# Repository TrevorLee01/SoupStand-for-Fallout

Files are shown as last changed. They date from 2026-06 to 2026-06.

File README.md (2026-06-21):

# Soup-Stand 🎧🦝 // FALLOUT PROJECT
A multifunctional pastel and tanuki (Soup!) themed headphone stand with integrated speaker, storage, and cable organization.

Created by Youna Son & Trevor Lee for Fallout / Hack Club.
✍️(◔◡◔)

ONSHAPE LINK: https://cad.onshape.com/documents/8000dcbb44917720ecbb4f72/w/cf3f842479549c0ffed44f74/e/c42a8c0b9d5092f488456cc3

  BOM INCLUDED IN THE FILES! "BOM.csv" 
or:
https://docs.google.com/spreadsheets/d/1DdpiUlOQK0JWII-2MIieYWEtMwIM88fONbokk5xA5AE/edit?gid=0#gid=0

______________


# What Is A Soup Stand ❓ο(=•ω＜=)ρ⌒☆
A Soup Stand is a hybrid desk accessory designed to combine organization, audio, and aesthetics into a single, cute tanuki.

The project combines:
- A headphone stand
- Speaker
- Compact desk organization
- Decorative accessory

The design was inspired by:
- pastel tech aesthetics (I've always wanted a cute set-up 💔)
- Japanese lifstyle product design (look how Muji designs their aesthetically pleasing stationary!)


+ gaming/anime desk culture:


But now... imagine the Soup Stand in these images

Unlike most headphone stads that are purely functional and even weirdly abstract looking, our product is designed to feel cozy. 

_________________

# Why It Was Made 🛠️ o(*￣▽￣*)o

We noticed that most desk accessories feel:
- boringggggggg
- overly industrial (late-stage capitalism tsk tsk)
- visually disconnected from modern aesthetic setups

At the same time, headphones are left:
- on desks (takes so much space on my limited desk space)
- hanging off monitors
- tangled in wires

So..
We wanted to create something that:
1) organizees a worspace
2) improves desk appearance
3) emotionally engaging rather than purely mechanical

A major goal of this project was combing hardware engineering (the opportunity fallout gives us) with product branding and visual interesting design

__________

# Features ✨   (*^▽^*)
## 🎧 Headphone Stand 
Supports over-ear headphones while keeping them accessible and off and desk surface 
## 🔊 Speaker
Internal space planned for small speaker 

~ plays your favorite song ~
## 🎨Decorative Design 

This structure is designed around 3D printing and prototyping!

________

# How It Works ╰(*°▽°*)╯

The headphones rest of the upper support section of the stand.

The lower body contains:
- eletronic compartment
- structural support (flat base)
- speakers

There are 3 buttons:
TOP: increase volume
MIDDLE: pause music/sound
BOTTOM: decrease volume

All 3 at once is the power on and off button

  !! POTENTIALLY:customizable parts ?? !!
  __________

  # How to build
  ______
  How to Assemble & Use Your Soup Stand
1) Print the Parts: Download the .step files from the repository and 3D print the upper headset support, main body, and base storage compartment.

2) Mount the Electronics: Secure your custom PCB inside the lower electronic compartment. Fit the speaker into its designated internal slot.

3) Route the Cables & Connect: Pass your speaker and power cables through the integrated cable organization channels out to the back of the stand.

4) Final Assembly: Align the upper support section with the main body and snap/screw them together.

5) How to Use: Place the Soup Stand on your desk and plug the power/audio cable into your computer or power source. Rest your over-ear headphones on Soup’s head to keep your desk clutter-free, use the lower tray for compact desk storage, and play your favorite music directly through the integrated speaker!

  # PICTURES!!!
  THIS OUR FINISHED CAD YAYYY (no color because we rendered it with color instead)

  

  

  THIS IS OUR PCB rah!!

  

  

  extra image of rendering not in the zine (NO FACE) :
  

# Credits
- Onshape (CAD)
- GitHub (here!)
- Canva (Zine)
- 3D printing
- and obviously... FALLOUT! since our headphone stand is based off the mascot Soup!

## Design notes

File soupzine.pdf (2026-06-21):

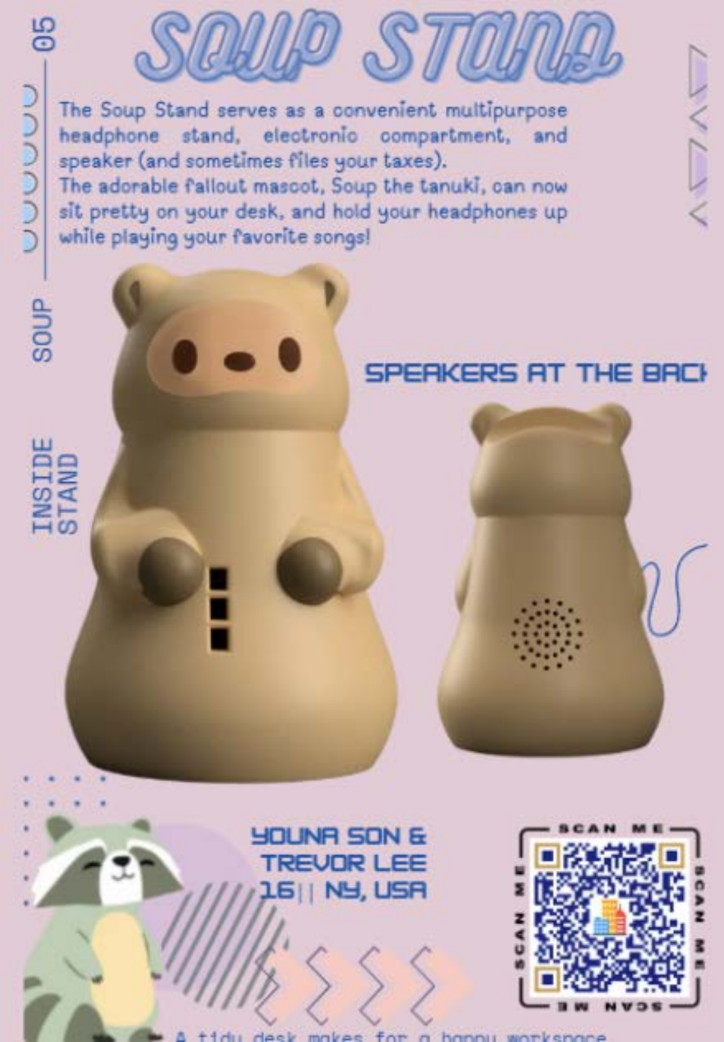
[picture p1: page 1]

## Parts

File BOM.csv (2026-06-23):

SOUPSTAND BILL OF MATERIALS
Total Cost
$ 62.19
Item | Indiv Costs | Quanities | Cost | Links to Order | Additional Notes
ESP32-S3-WROOM-1-N16R8 MCU | $ 6.76 | 1 | $ 6.76 | https://www.digikey.com/en/products/detail/espressif-systems/ESP32-S3-WROOM-1-N16R8/16162642
MAX98357AETE+T Amplifier | $ 3.73 | 1 | $ 3.73 | https://www.digikey.com/en/products/detail/analog-devices-inc-maxim-integrated/MAX98357AETE-T/4936122
AP2112K-3.3TRG1 Voltage Regulator | $ 0.25 | 1 | $ 0.25 | https://www.digikey.com/en/products/detail/diodes-incorporated/AP2112K-3-3TRG1/4470746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
MCP73831T-2ATI/OT Charger | $ 0.76 | 1 | $ 0.76 | https://www.digikey.com/en/products/detail/microchip-technology/MCP73831T-2ATI-OT/964303
TYPE-C-31-M-12 USB-C Receptable | $ 0.19 | 5 | $ 0.93 | https://www.lcsc.com/product-detail/C165948.html | 4 extra, only available in bulk
B2B-PH-K-S Connector | $ 0.11 | 1 | $ 0.11 | https://www.digikey.com/en/products/detail/jst-sales-america-inc/B2B-PH-K-S/926611
M20-9990246 Connector | $ 0.10 | 1 | $ 0.10 | https://www.digikey.com/en/products/detail/harwin-inc/M20-9990246/3728226?s=N4IgTCBcDaILZgAwFoCc7FgCwDYQF0BfIA
OS102011MS2QN1 Slide Switch | $ 0.80 | 1 | $ 0.80 | https://www.digikey.com/en/products/detail/c-k/OS102011MS2QN1/411602
1825910-6 Tactile Switch | $ 0.13 | 3 | $ 0.39 | https://www.digikey.com/en/products/detail/te-connectivity-alcoswitch-switches/1825910-6/1632536
PTS645SM43SMTR92 LFS Tactile Switch | $ 0.36 | 1 | $ 0.36 | https://www.digikey.com/en/products/detail/c-k/PTS645SM43SMTR92-LFS/1146840
CL21A106KQFNNNE Capacitor | $ 0.10 | 4 | $ 0.40 | https://www.digikey.com/en/products/detail/samsung-electro-mechanics/CL21A106KQFNNNE/3886780
C0603C104K3RACTU Capacitor | $ 0.10 | 6 | $ 0.60 | https://www.digikey.com/en/products/detail/kemet/C0603C104K3RACTU/416044
C0603C105K4RACTU Capacitor | $ 0.10 | 1 | $ 0.10 | https://www.digikey.com/en/products/detail/kemet/C0603C105K4RACTU/2199788
16YXJ220MT16.3X11 Electrolytic Capacitor | $ 0.30 | 1 | $ 0.30 | https://www.digikey.com/en/products/detail/rubycon/16YXJ220MT16-3X11/3134826
LTST-C191KFKT LED | $ 0.11 | 1 | $ 0.11 | https://www.digikey.com/en/products/detail/liteon/LTST-C191KFKT/386833
RC0603FR-075K1L Resistor | $ 0.10 | 2 | $ 0.20 | https://www.digikey.com/en/products/detail/yageo/RC0603FR-075K1L/727268
RC0603FR-0710KL Resistor | $ 0.10 | 2 | $ 0.20 | https://www.digikey.com/en/products/detail/yageo/RC0603FR-0710KL/726880
RR0816P-202-D Resistor | $ 0.10 | 1 | $ 0.10 | https://www.digikey.com/en/products/detail/susumu/RR0816P-202-D/432192
RC0603FR-07330RL Resistor | $ 0.10 | 1 | $ 0.10 | https://www.digikey.com/en/products/detail/yageo/RC0603FR-07330RL/727162
RMCF0603FT300K Resistor | $ 0.10 | 1 | $ 0.10 | https://www.digikey.com/en/products/detail/stackpole-electronics-inc/RMCF0603FT300K/1760826
PCB | $ 0.40 | 5 | $ 2.00 | https://cart.jlcpcb.com/quote?stencilLayer=2&stencilWidth=100&stencilLength=100&stencilCounts=5&plateType=1
PLA Housing | $ - |  | $ -
M3 x 10mm Socket Cap Head Screws | $ 0.33 | 6 | $ 1.98 | https://accu-components.com/us/metric-cap-head-screws/16004-SSCF-M3-10-12-9
M3 x 5mm Socket Cap Head Screws | $ 0.45 | 4 | $ 1.80 | https://accu-components.com/us/metric-cap-head-screws/16001-SSCF-M3-5-12-9
NS50D-0802-L82-01 Speaker | $ 2.40 | 1 | $ 2.40 | https://www.digikey.com/en/products/detail/nac-holdings-limited/NS50D-0802-L82-01/15859761
BK-18650-PC6 Battery Mount | $ 5.24 | 1 | $ 5.24 | https://www.digikey.com/en/products/detail/mpd-memory-protection-devices-/BK-18650-PC6/2330514
12895 Batteries | $ 10.79 | 3 | $ 32.37 | https://www.digikey.com/en/products/detail/sparkfun-electronics/12895/5271298

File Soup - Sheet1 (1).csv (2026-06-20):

SOUPSTAND BILL OF MATERIALS
Total Cost
$ 24.58
Item | Indiv Costs | Quanities | Cost | Links to Order | Additional Notes
ESP32-S3-WROOM-1-N16R8 | $ 6.76 | 1 | $ 6.76 | https://www.digikey.com/en/products/detail/espressif-systems/ESP32-S3-WROOM-1-N16R8/16162642
MAX98357AETE+T | $ 3.73 | 1 | $ 3.73 | https://www.digikey.com/en/products/detail/analog-devices-inc-maxim-integrated/MAX98357AETE-T/4936122
AP2112K-3.3TRG1 | $ 0.25 | 1 | $ 0.25 | https://www.digikey.com/en/products/detail/diodes-incorporated/AP2112K-3-3TRG1/4470746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
MCP73831T-2ATI/OT | $ 0.76 | 1 | $ 0.76 | https://www.digikey.com/en/products/detail/microchip-technology/MCP73831T-2ATI-OT/964303
TYPE-C-31-M-12 | $ 0.19 | 5 | $ 0.93 | https://www.lcsc.com/product-detail/C165948.html | 4 extra, only available in bulk
B2B-PH-K-S | $ 0.11 | 1 | $ 0.11 | https://www.digikey.com/en/products/detail/jst-sales-america-inc/B2B-PH-K-S/926611
M20-9990246 | $ 0.10 | 1 | $ 0.10 | https://www.digikey.com/en/products/detail/harwin-inc/M20-9990246/3728226?s=N4IgTCBcDaILZgAwFoCc7FgCwDYQF0BfIA
OS102011MS2QN1 | $ 0.80 | 1 | $ 0.80 | https://www.digikey.com/en/products/detail/c-k/OS102011MS2QN1/411602
1825910-6 | $ 0.13 | 3 | $ 0.39 | https://www.digikey.com/en/products/detail/te-connectivity-alcoswitch-switches/1825910-6/1632536
PTS645SM43SMTR92 LFS | $ 0.36 | 1 | $ 0.36 | https://www.digikey.com/en/products/detail/c-k/PTS645SM43SMTR92-LFS/1146840
CL21A106KQFNNNE | $ 0.10 | 4 | $ 0.40 | https://www.digikey.com/en/products/detail/samsung-electro-mechanics/CL21A106KQFNNNE/3886780
C0603C104K3RACTU | $ 0.10 | 6 | $ 0.60 | https://www.digikey.com/en/products/detail/kemet/C0603C104K3RACTU/416044
C0603C105K4RACTU | $ 0.10 | 1 | $ 0.10 | https://www.digikey.com/en/products/detail/kemet/C0603C105K4RACTU/2199788
16YXJ220MT16.3X11 | $ 0.30 | 1 | $ 0.30 | https://www.digikey.com/en/products/detail/rubycon/16YXJ220MT16-3X11/3134826
LTST-C191KFKT | $ 0.11 | 1 | $ 0.11 | https://www.digikey.com/en/products/detail/liteon/LTST-C191KFKT/386833
RC0603FR-075K1L | $ 0.10 | 2 | $ 0.20 | https://www.digikey.com/en/products/detail/yageo/RC0603FR-075K1L/727268
RC0603FR-0710KL | $ 0.10 | 2 | $ 0.20 | https://www.digikey.com/en/products/detail/yageo/RC0603FR-0710KL/726880
RR0816P-202-D | $ 0.10 | 1 | $ 0.10 | https://www.digikey.com/en/products/detail/susumu/RR0816P-202-D/432192
RC0603FR-07330RL | $ 0.10 | 1 | $ 0.10 | https://www.digikey.com/en/products/detail/yageo/RC0603FR-07330RL/727162
RMCF0603FT300K | $ 0.10 | 1 | $ 0.10 | https://www.digikey.com/en/products/detail/stackpole-electronics-inc/RMCF0603FT300K/1760826
PCB | $ 0.40 | 5 | $ 2.00 | https://cart.jlcpcb.com/quote?stencilLayer=2&stencilWidth=100&stencilLength=100&stencilCounts=5&plateType=1
PLA Housing | $ - |  | $ -
M3 x 10mm Socket Cap Head Screws | $ 0.33 | 6 | $ 1.98 | https://accu-components.com/us/metric-cap-head-screws/16004-SSCF-M3-10-12-9
M3 x 5mm Socket Cap Head Screws | $ 0.45 | 4 | $ 1.80 | https://accu-components.com/us/metric-cap-head-screws/16001-SSCF-M3-5-12-9
NS50D-0802-L82-01 Speaker | $ 2.40 | 1 | $ 2.40 | https://www.digikey.com/en/products/detail/nac-holdings-limited/NS50D-0802-L82-01/15859761

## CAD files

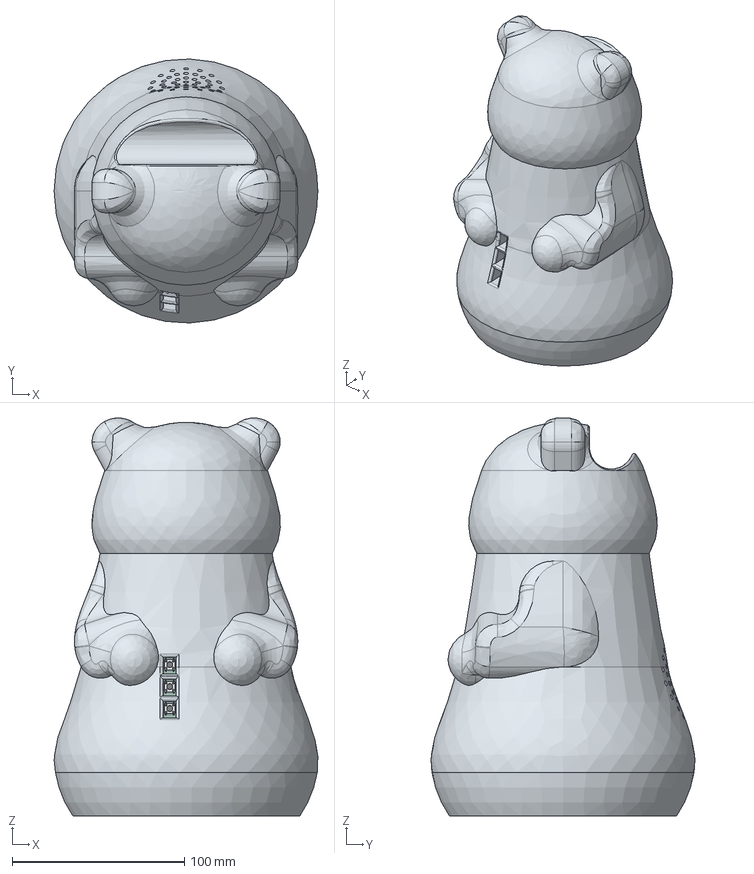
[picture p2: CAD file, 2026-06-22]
CAD/FINAL ASSEMBLY.step
153.2 x 153.2 x 231.1 mm
SOUP pcb_silkscreen x 159
SOUP pcb_copper x 77
SOUP pcb_via x 34
C_0805_2012Metric x 4
CP_Radial_D63mm_P250mm
SOT-23-5 x 2
soup_head
SOUP pcb_PCB
M3-5 x 4
18650 Battery x 3
SW_PUSH_6mm x 3
C_0603_1608Metric x 7
R_0603_1608Metric x 7
PinHeader_1x02_P254mm_Vertical
M3-10 (2) (1) x 6
LED_0603_1608Metric
SOUP pcb_soldermask x 2
SW_SPST_PTS645Sx43SMTR92
soup_body_top
soup_body_bottom
JST_B2B_PH_K
SW_Slide_SPDT_Straight_CK_OS102011MS2Q x 6
ESP32-S3-WROOM-1 x 52
shield
tongue
contact_court_007
contact_002
contact_001
contact_court_004
contact_003
contact_court_003
contact_006
contact_005
contact_008
contact_007
contact_court_008
contact_court_005
contact_004
contact_court_001
contact_court_006
contact_court_002
pin_007
pin_010
pin_005
pin_003
pin_012
pin_009
pin_016
pin_002
pin_004
pin_014
pin_013
pin_008
pin_006
pin_001
pin_011
pin_015
BH-18650_CONTACT x 6
BH-18650_BODY

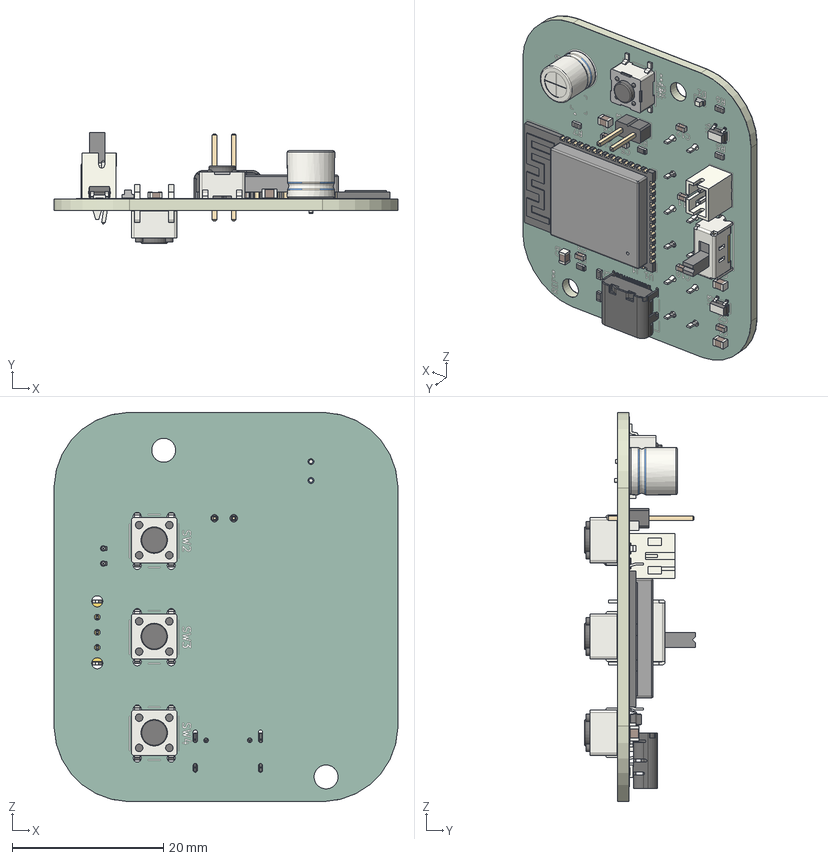
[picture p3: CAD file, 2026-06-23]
PCB Files/SOUP pcb.step
45.5 x 14.7 x 51.5 mm
SOUP pcb_via x 34
SOUP pcb_copper x 77
C_0603_1608Metric x 7
SW_PUSH_6mm x 3
SOUP pcb_silkscreen x 159
SOT-23-5 x 2
JST_B2B_PH_K
C_0805_2012Metric x 4
R_0603_1608Metric x 7
SOUP pcb_PCB
SW_SPST_PTS645Sx43SMTR92
PinHeader_1x02_P254mm_Vertical
LED_0603_1608Metric
SOUP pcb_soldermask x 2
CP_Radial_D63mm_P250mm
SW_Slide_SPDT_Straight_CK_OS102011MS2Q x 6
ESP32-S3-WROOM-1 x 52
tongue
shield
pin_015
pin_004
pin_003
pin_014
pin_001
pin_010
pin_009
pin_005
pin_011
pin_012
pin_006
pin_007
pin_013
pin_002
pin_008
pin_016
contact_court_005
contact_court_008
contact_court_002
contact_002
contact_court_004
contact_court_001
contact_006
contact_004
contact_court_006
contact_court_003
contact_court_007
contact_005
contact_007
contact_003
contact_001
contact_008

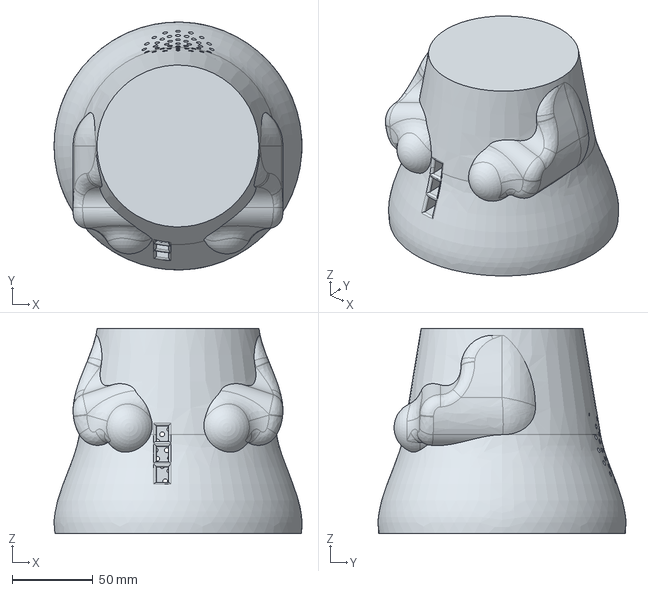
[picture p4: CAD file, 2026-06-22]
CAD/soup_body_top.step
153.3 x 153.3 x 127.0 mm

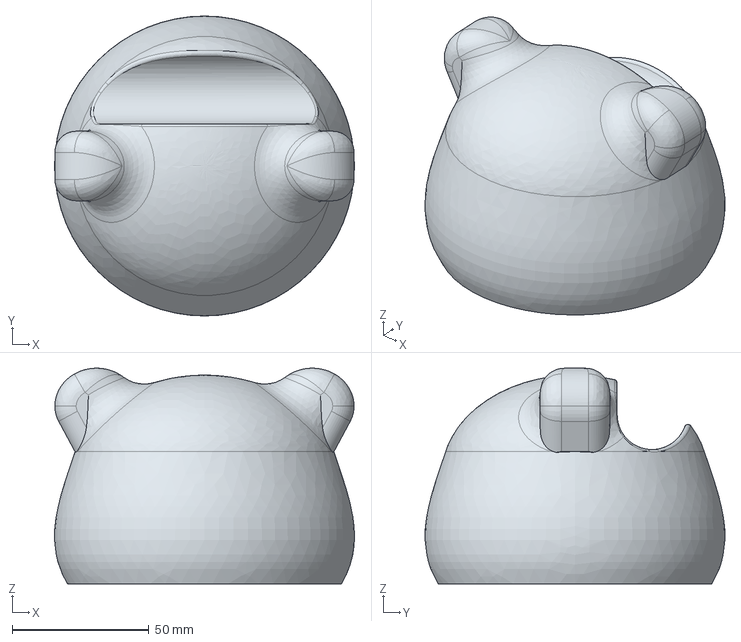
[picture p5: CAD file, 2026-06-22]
CAD/soup_head.step
109.5 x 109.5 x 78.7 mm

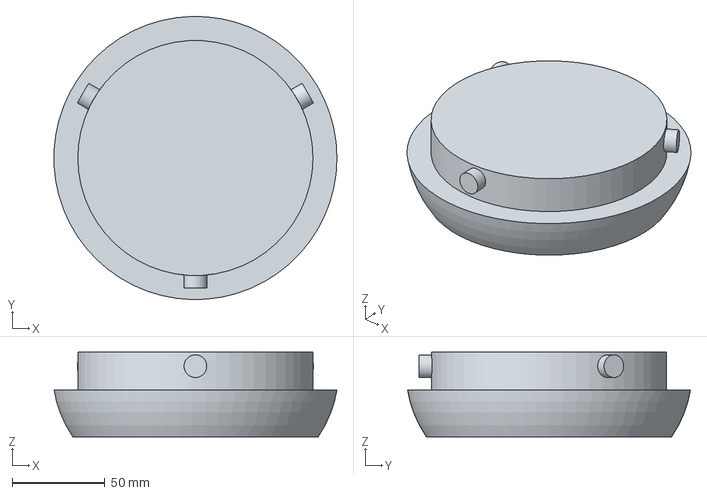
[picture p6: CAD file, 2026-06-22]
CAD/soup_body_bottom.step
152.3 x 152.3 x 45.7 mm

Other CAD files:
CAD/soup_body_bottom.stl
CAD/soup_body_top.stl
CAD/soup_head.stl

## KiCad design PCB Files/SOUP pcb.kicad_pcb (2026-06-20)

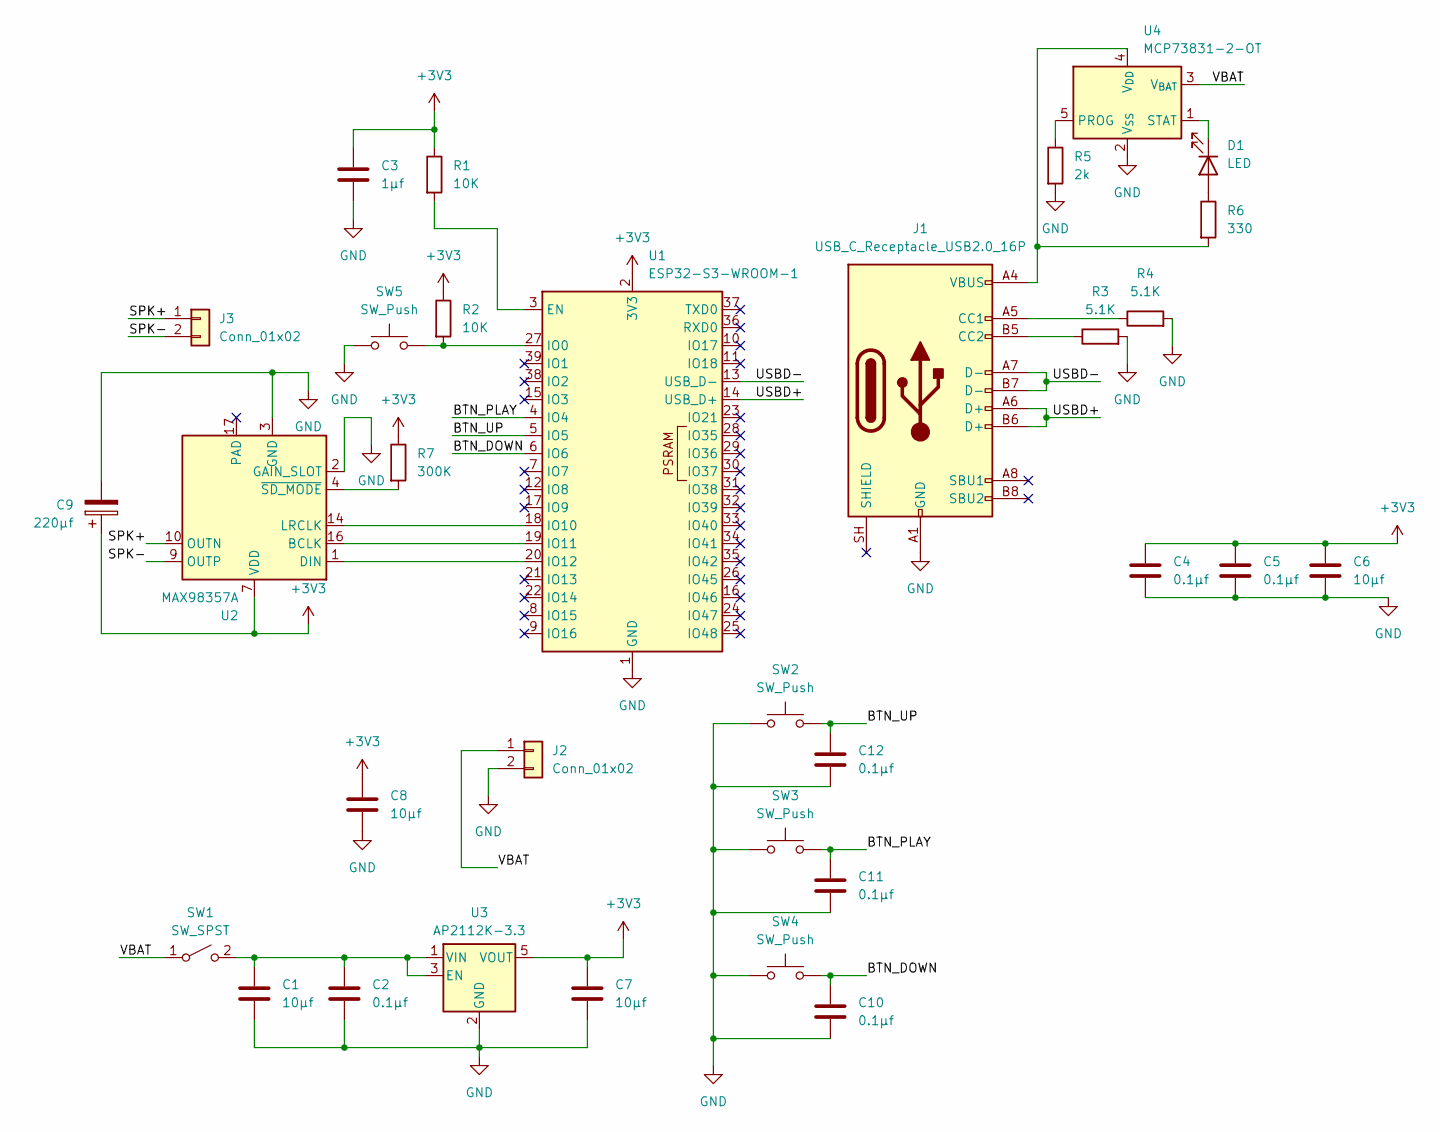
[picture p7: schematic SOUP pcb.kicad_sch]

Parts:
C1, C6, C7, C8: 10μf; C_0805_2012Metric
C2, C4, C5, C10, C11, C12: 0.1μf; C_0603_1608Metric
C3: 1μf; C_0603_1608Metric
C9: 220μf; CP_Radial_D6.3mm_P2.50mm
D1: LED; LED_0603_1608Metric
J1: USB_C_Receptacle_USB2.0_16P; USB_C_Receptacle_HRO_TYPE-C-31-M-12
J2: Conn_01x02; JST_PH_B2B-PH-K_1x02_P2.00mm_Vertical
J3: Conn_01x02; PinHeader_1x02_P2.54mm_Vertical
R1, R2: 10K; R_0603_1608Metric
R3, R4: 5.1K; R_0603_1608Metric
R5: 2k; R_0603_1608Metric
R6: 330; R_0603_1608Metric
R7: 300K; R_0603_1608Metric
SW1: SW_SPST; SW_Slide_SPDT_Straight_CK_OS102011MS2Q
SW2, SW3, SW4: SW_Push; SW_PUSH_6mm
SW5: SW_Push; SW_SPST_PTS645Sx43SMTR92
U1: ESP32-S3-WROOM-1
U2: MAX98357A; TQFN-16-1EP_3x3mm_P0.5mm_EP1.23x1.23mm
U3: AP2112K-3.3; SOT-23-5
U4: MCP73831-2-OT; SOT-23-5

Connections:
+3V3: C3.1, C4.2, C5.2, C6.2, C7.1, C8.1, C9.1, R1.1, R2.1, R7.1, U1.2 (3V3), U2.7 (VDD), U2.8 (VDD), U3.5 (VOUT)
/BTN_DOWN: C10.1, SW4.2, U1.6 (IO6)
/BTN_PLAY: C11.1, SW3.2, U1.4 (IO4)
/BTN_UP: C12.1, SW2.2, U1.5 (IO5)
/SPK+: J3.1, U2.10 (OUTN)
/SPK-: J3.2, U2.9 (OUTP)
/USBD+: J1.A6 (D+), J1.B6 (D+), U1.14 (USB_D+)
/USBD-: J1.A7 (D-), J1.B7 (D-), U1.13 (USB_D-)
/VBAT: J2.1, SW1.1 (A), U4.3 (V_{BAT})
GND: C1.2, C2.2, C3.2, C4.1, C5.1, C6.1, C7.2, C8.2, C9.2, C10.2, C11.2, C12.2, J1.A1 (GND), J1.A12 (GND), J1.B1 (GND), J1.B12 (GND), J2.2, R3.2, R4.2, R5.2, SW2.1, SW3.1, SW4.1, SW5.1, U1.1 (GND), U1.40 (GND), U1.41 (GND), U2.2 (GAIN_SLOT), U2.3 (GND), U2.11 (GND), U2.15 (GND), U3.2 (GND), U4.2 (V_{SS})
unnamed: D1.2 (A), R6.1
unnamed: D1.1 (K), U4.1 (STAT)
unnamed: J1.A5 (CC1), R4.1
unnamed: J1.B5 (CC2), R3.1
unnamed: C1.1, C2.1, SW1.2 (B), U3.1 (VIN), U3.3 (EN)
unnamed: R1.2, U1.3 (EN)
unnamed: R2.2, SW5.2, U1.27 (IO0)
unnamed: U1.18 (IO10), U2.14 (LRCLK)
unnamed: U1.19 (IO11), U2.16 (BCLK)
unnamed: U1.20 (IO12), U2.1 (DIN)
unnamed: R7.2, U2.4 (~SD_MODE)
unnamed: R5.1, U4.5 (PROG)
unnamed: J1.A4 (VBUS), J1.A9 (VBUS), J1.B4 (VBUS), J1.B9 (VBUS), R6.2, U4.4 (V_{DD})

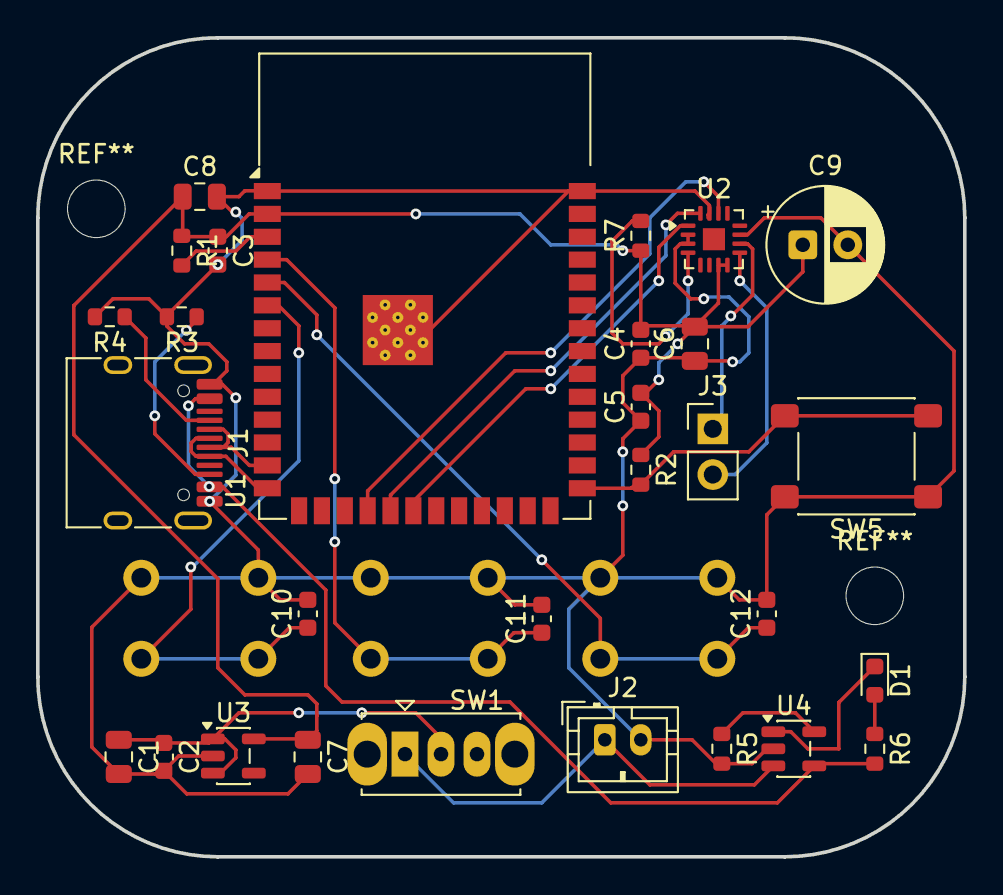
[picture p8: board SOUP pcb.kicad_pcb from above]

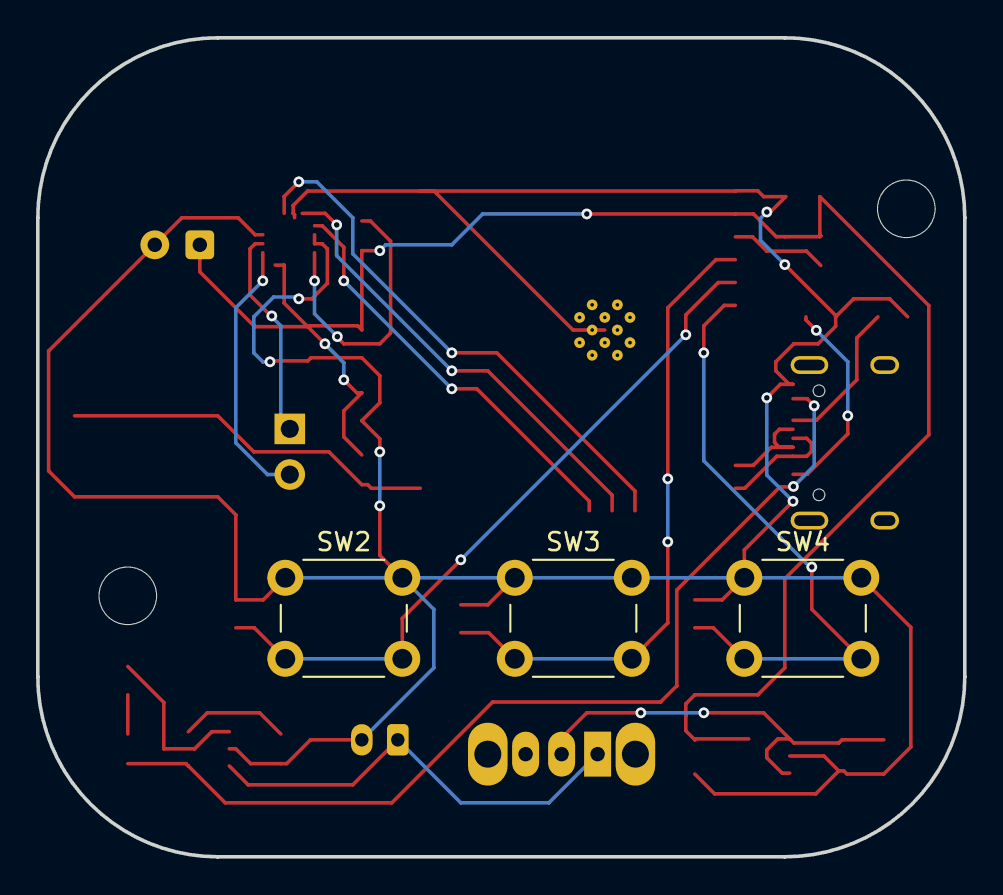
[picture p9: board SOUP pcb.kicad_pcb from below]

Board: 2 copper layers, 51.5 x 45.5 mm, 32 parts (3 on the bottom side), 23 nets.

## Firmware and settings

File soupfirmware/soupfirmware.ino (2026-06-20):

#include <Arduino.h>
#include <WiFi.h>
#include "Audio.h"

//==================================================================
//firmware

//wifi placeholders (replace later with real wifi network)
#define WIFI_SSID "wifiname"
#define WIFI_PASSWORD "wifipassword"

//audio (placeholder)
#define AUDIO_STREAM_URL "streamurl"


//i25 pins from schematic
#define I2S_LRC 10
#define I2S_BCLK 11
#define I2S_DOUT 12

//button pins 
#define BTN_PLAY 4
#define BTN_UP 5
#define BTN_DOWN 6

//probably 0-21 in volunme right?
#define MIN_VOLUME 0
#define MAX_VOLUME 21
#define START_VOLUME 12

#define DEBOUNCE_MS 40

class DebouncedButton{
  private: 
    uint8_t pin;
    bool stableState;
    bool lastReading;
    unsigned long lastChangeTime;

  public:
    DebouncedButton(uint8_t buttonPin)
    : pin(buttonPin), stableState(HIGH), lastReading(HIGH), lastChangeTime(0) {

    }
    void begin(){
      pinMode(pin, INPUT_PULLUP);
      stableState = digitalRead(pin);
      lastReading = stableState;
    }

    bool wasPressed(){
        bool reading = digitalRead(pin);

        if(reading != lastReading){
          lastChangeTime = millis();
          lastReading = reading;
        }

        if((millis()- lastChangeTime) > DEBOUNCE_MS && reading!= stableState){
          stableState = reading;
        
          if(stableState == LOW){
            return true;
          }
        }
        return false;
    }
};

class HeadphoneStandPlayer{
  private:
    Audio audio;
    DebouncedButton playButton;
    DebouncedButton volumeUpButton;
    DebouncedButton volumeDownButton;

    int volume;
    bool streamStarted;
    bool streamPaused;

    public:
      HeadphoneStandPlayer()
      : playButton(BTN_PLAY), volumeUpButton(BTN_UP), volumeDownButton(BTN_DOWN),volume(START_VOLUME), streamStarted(false),
      streamPaused(false){}

      void begin(){
        playButton.begin();
        volumeUpButton.begin();
        volumeDownButton.begin();

        audio.setPinout(I2S_BCLK, I2S_LRC, I2S_DOUT);
        audio.setVolume(volume);

        Serial.println("Audio hardware ready ヽ(✿ﾟ▽ﾟ)ノ");
        Serial.println("Press PLAY to start the Wi-Fi stream o(*^＠^*)o");

      }

      void update(){
        audio.loop();
        if(playButton.wasPressed()){
          handlePlayButton();
        }

        if(volumeUpButton.wasPressed()){
          changeVolume(1);
        }

        if(volumeDownButton.wasPressed()){
          changeVolume(-1);
        }
      }
  private: 
    void handlePlayButton(){
      if(!streamStarted){
        Serial.println("PLAY pressed: starting stream (☞ﾟヮﾟ)☞ ☜(ﾟヮﾟ☜)");
        audio.connecttohost(AUDIO_STREAM_URL);
        streamStarted = true;
        streamPaused = false;
        return;
      }

      audio.pauseResume();
      streamPaused = !streamPaused;
    }
    void changeVolume(int amount){
      volume+= amount;

      if(volume<MIN_VOLUME){
        volume = MIN_VOLUME;
      }

      if(volume>MAX_VOLUME){
        volume = MAX_VOLUME;
      }

      audio.setVolume(volume);
      Serial.print("Volume: ");
      Serial.println(volume);
    }
};

HeadphoneStandPlayer player;

void connectToWifi(){
  Serial.print("Connecting to Wi-Fi o(￣▽￣)ｄ");

  WiFi.mode(WIFI_STA);
  WiFi.begin(WIFI_SSID, WIFI_PASSWORD);

  while(WiFi.status() != WL_CONNECTED){
    delay(250);
    Serial.print(".");
  }

  Serial.println();
  Serial.println("Wi-Fi connected.");
  Serial.print("IP address: ");
  Serial.println(WiFi.localIP());
}

void setup(){
  Serial.begin(115200);
  delay(500);

  connectToWifi();
  player.begin();
}

void loop(){
  player.update();
}

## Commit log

2026-06-20 Create pcb
2026-06-20 Rename SOUP pcb (1).kicad_sch to SOUP pcb.kicad_sch
    [SOUP pcb.kicad_sch]
2026-06-20 Rename Soup - Sheet1.csv to BOM.csv
    [BOM.csv]
2026-06-20 Rename Soup - Sheet1 (1).csv to bom.csv
    [bom.csv]
2026-06-21 renaming files
    [SOUP pcb.kicad_pcb, SOUP pcb.kicad_sch]
2026-06-21 Revise README with features and assembly details
    Updated README to include additional features, assembly instructions, and images for the Soup Stand project.
